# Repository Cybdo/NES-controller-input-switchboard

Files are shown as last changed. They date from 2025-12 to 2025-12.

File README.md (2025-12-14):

# NES-controller-input-switchboard
The switchboard is essentially a 2:2 6-channel multiplexer, with one output being routed to an RP2040 for processing and a USB Keyboard output as opposed to exposing it directly.
Part of a larger homemade arcade project, I want to be able to have a embedded controller with arcade buttons and an external connector for external controllers or a light zapper, to be routed to an NES for retro games, as well as a ZimaBoard or Pi 4 (or other computer, via USB) for modern games

## Features:
- 6 channel 2:2 multiplexer
- ability to switch a power line
- NES Controller signal decode
- USB-HID keyboard output for decoded signals
- Separate data and power USB-C connectors
- ~~Exposed GPIO for expansion~~



## Schematics




## Board


## Firmware
Thanks to [Print 'N Play](https://www.youtube.com/@PrintNPlay) ([Github](https://github.com/printnplay)) for opensourcing a [CircuitPython Script](https://github.com/printnplay/Pico-MicroPython/blob/main/NES2USB.py) that already performs my desired functionailty. If I feel up to it I may rewrite it myself in the future.

## JLCPCB order


## Credits
This project uses work from:
- [Kicad](https://www.kicad.org/)
- [CircuitPython](https://circuitpython.org/)
- [Print 'N Play](https://github.com/printnplay)
- [Hack Club!](https://hackclub.com)

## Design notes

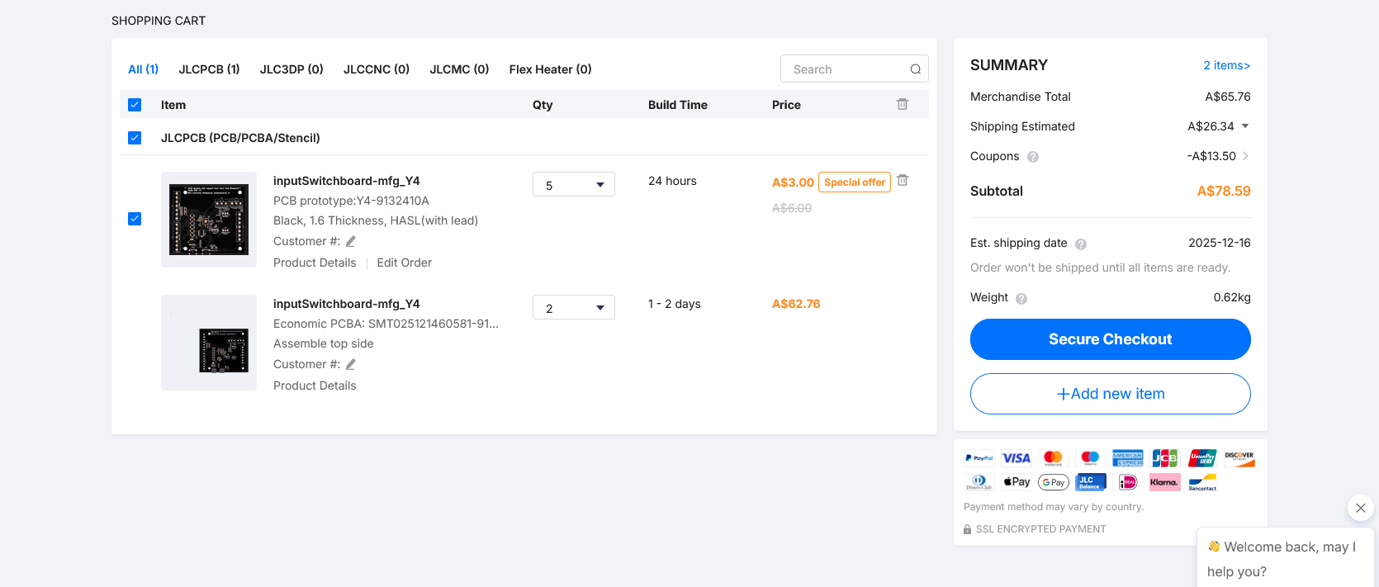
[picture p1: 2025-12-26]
jlcpcb-cart.png

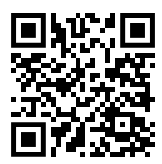
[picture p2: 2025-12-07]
inputSwitchboard/rickroll.bmp

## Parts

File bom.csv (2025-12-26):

Quantity | Item | Price each (AUD) | Price each (USD @ 0.67 USD for 1 AUD) | Price total (USD) | Source
1 | PCB | 3 | 2.01 | 2.01 | JLCPCB
1 | PCBA | 62.76 | 42.05 | 42.05 | JLCPCB
1 | Shipping - PCB | 26.34 | 17.65 | 17.65 | UPS Worldwide Express Saver
2 | NES controller extension cable | 1.59 | 1.07 | 2.13 | Aliexpress - 3Cc Game Store (https://www.aliexpress.com/item/1005003367500150.html)
1 | Shipping - Aliexpress | 5.94 | 3.98 | 3.98 | Aliexpress
 |  |  | total (USD) | 67.82

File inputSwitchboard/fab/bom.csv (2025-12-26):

Id | Designator | Footprint | Quantity | Comment | Supplier and ref
1 | , |  | 2
2 | C5,C13 | C_0201_0603Metric | 2 | 1uF
3 | C11,C15,C16,C12,C6,C10,C8,C14,C9,C7 | C_0201_0603Metric | 10 | 100nF
4 | C17,C18 | C_0201_0603Metric | 2 | 15pF
5 | Y1 | XTAL_ABM8-272-T3 | 1 | ABM8-272-T3
6 | J1 | TYPE-C-31-M-12 | 1 | DATA
7 | R6,R17,R7,R5,R8,R15,R16 | R_0603_1608Metric | 7 | 4k7R
8 | U9 | TSSOP-20_4.4x6.5mm_P0.65mm | 1 | TXS0108EPW
9 | J2 | TYPE-C-31-M-12 | 1 | POWER
10 | C2,C1,C4,C3 | C_0201_0603Metric | 4 | 10uF
11 | R11,R3,R1,R10,R2 | R_0603_1608Metric | 5 | 5k1R
12 | D2 | LED_0201_0603Metric | 1 | STATUS
13 | R19,R18 | R_0603_1608Metric | 2 | 6k8R
14 | U4,U8,U3,U7,U5,U6 | MSOP-10-1EP_3x3mm_P0.5mm_EP1.68x1.88mm | 6 | CH442E
15 | R9,R4 | R_0603_1608Metric | 2 | 470R
16 | R12,R14 | R_0603_1608Metric | 2 | 1kR
17 | U12,U11 | SOT-23-5 | 2 | ~
18 | U10 | SOIC-8_5.3x5.3mm_P1.27mm | 1 | W25Q128JVS
19 | U2 | QFN-56-1EP_7x7mm_P0.4mm_EP3.2x3.2mm | 1 | RP2040
20 | D1 | LED_0201_0603Metric | 1 | PWR_LED
21 | R13 | R_0603_1608Metric | 1 | 10kR
22 | U1 | SOT-223-3_TabPin2 | 1 | AMS1117-3.3

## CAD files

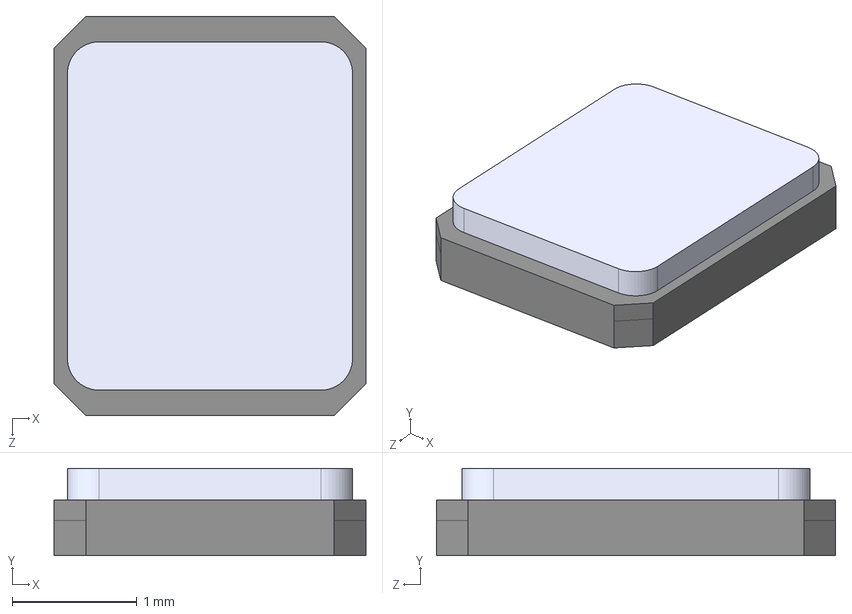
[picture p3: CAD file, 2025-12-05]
inputSwitchboard/imports/ABM8-272-T3.step
2.50 x 0.7 x 3.20 mm

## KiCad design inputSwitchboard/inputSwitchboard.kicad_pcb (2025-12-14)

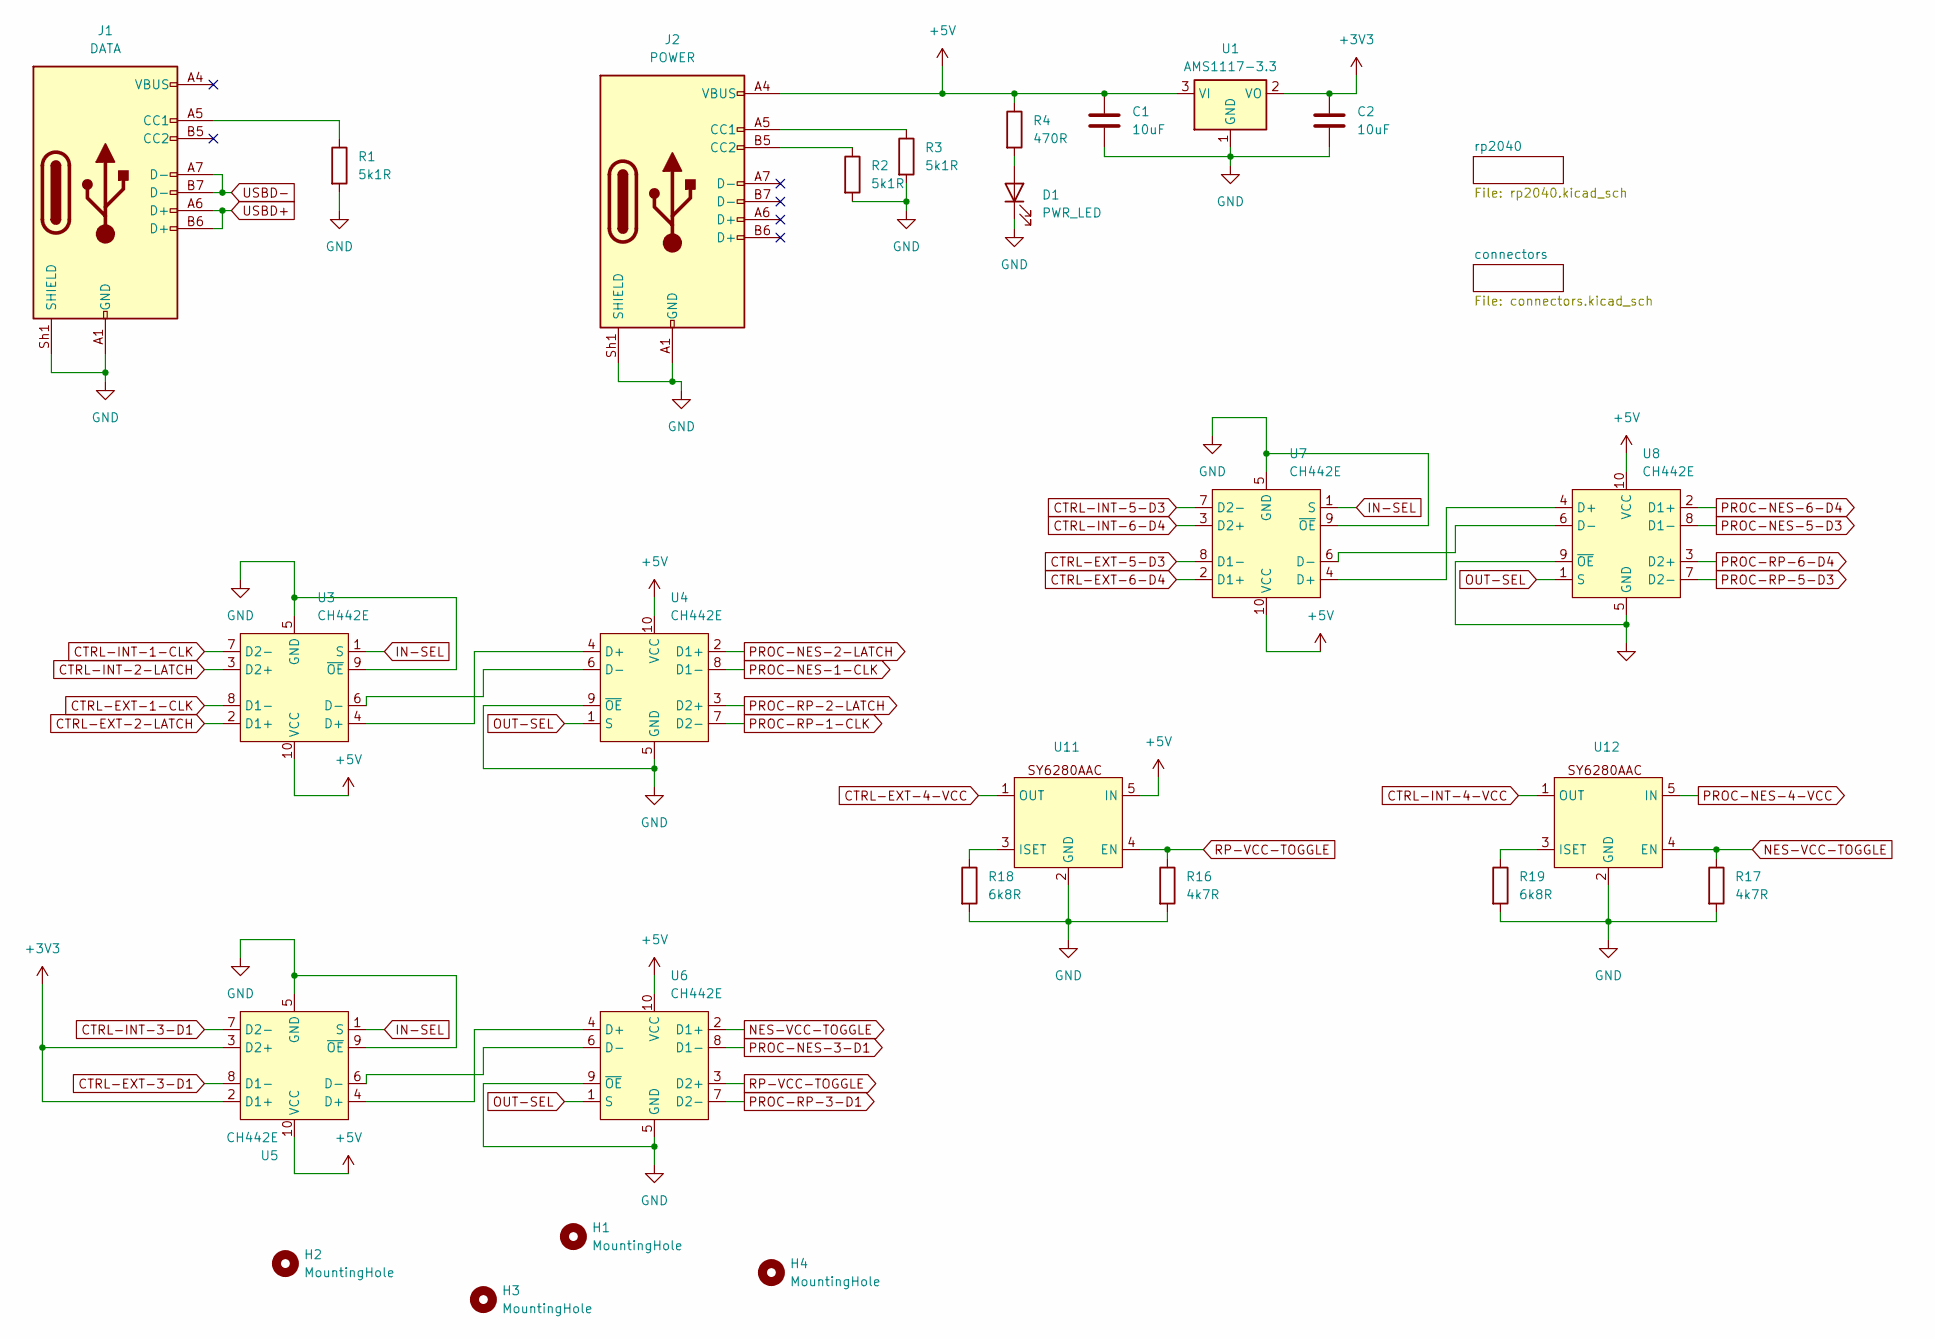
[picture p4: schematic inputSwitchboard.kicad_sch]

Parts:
C1, C2: 10uF; C_0201_0603Metric
D1: PWR_LED; LED_0603_1608Metric
H1, H2, H3, H4: MountingHole; MountingHole_4.3mm_M4
J1: DATA; TYPE-C-31-M-12
J2: POWER; TYPE-C-31-M-12
R1, R2, R3: 5k1R; R_0603_1608Metric
R4: 470R; R_0603_1608Metric
R16, R17: 4k7R; R_0603_1608Metric
R18, R19: 6k8R; R_0603_1608Metric
U1: AMS1117-3.3; SOT-223-3_TabPin2
U3, U4, U5, U6, U7, U8: CH442E; VSSOP-10_3x3mm_P0.5mm
U11, U12: SOT-23-5

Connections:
+3V3: C2.1, U1.2 (VO), U5.2 (D1+), U5.3 (D2+); also elsewhere on the board
+5V: C1.1, J2.A4 (VBUS), J2.A9 (VBUS), J2.B4 (VBUS), J2.B9 (VBUS), R4.1, U1.3 (VI), U3.10 (VCC), U4.10 (VCC), U5.10 (VCC), U6.10 (VCC), U7.10 (VCC), U8.10 (VCC), U11.5 (IN); also elsewhere on the board
CTRL-EXT-1-CLK: U3.8 (D1-); also elsewhere on the board
CTRL-EXT-2-LATCH: U3.2 (D1+); also elsewhere on the board
CTRL-EXT-3-D1: U5.8 (D1-); also elsewhere on the board
CTRL-EXT-4-VCC: U11.1 (OUT); also elsewhere on the board
CTRL-EXT-5-D3: U7.8 (D1-); also elsewhere on the board
CTRL-EXT-6-D4: U7.2 (D1+); also elsewhere on the board
CTRL-INT-1-CLK: U3.7 (D2-); also elsewhere on the board
CTRL-INT-2-LATCH: U3.3 (D2+); also elsewhere on the board
CTRL-INT-3-D1: U5.7 (D2-); also elsewhere on the board
CTRL-INT-4-VCC: U12.1 (OUT); also elsewhere on the board
CTRL-INT-5-D3: U7.7 (D2-); also elsewhere on the board
CTRL-INT-6-D4: U7.3 (D2+); also elsewhere on the board
GND: C1.2, C2.2, D1.1 (K), J1.A1 (GND), J1.A12 (GND), J1.B1 (GND), J1.B12 (GND), J1.Sh1 (SHIELD), J2.A1 (GND), J2.A12 (GND), J2.B1 (GND), J2.B12 (GND), J2.Sh1 (SHIELD), R1.2, R2.2, R3.2, R16.2, R17.2, R18.2, R19.2, U1.1 (GND), U3.5 (GND), U3.9 (~OE), U4.5 (GND), U4.9 (~OE), U5.5 (GND), U5.9 (~OE), U6.5 (GND), U6.9 (~OE), U7.5 (GND), U7.9 (~OE), U8.5 (GND), U8.9 (~OE), U11.2 (GND), U12.2 (GND); also elsewhere on the board
IN-SEL: U3.1 (S), U5.1 (S), U7.1 (S); also elsewhere on the board
NES-VCC-TOGGLE: R17.1, U6.2 (D1+), U12.4 (EN)
unnamed: D1.2 (A), R4.2
unnamed: J1.A5 (CC1), R1.1
unnamed: J2.A5 (CC1), R3.1
unnamed: J2.B5 (CC2), R2.1
unnamed: U3.4 (D+), U4.4 (D+)
unnamed: U3.6 (D-), U4.6 (D-)
unnamed: U5.4 (D+), U6.4 (D+)
unnamed: U5.6 (D-), U6.6 (D-)
unnamed: U7.4 (D+), U8.4 (D+)
unnamed: U7.6 (D-), U8.6 (D-)
unnamed: R18.1, U11.3 (ISET)
unnamed: R19.1, U12.3 (ISET)
OUT-SEL: U4.1 (S), U6.1 (S), U8.1 (S); also elsewhere on the board
PROC-NES-1-CLK: U4.8 (D1-); also elsewhere on the board
PROC-NES-2-LATCH: U4.2 (D1+); also elsewhere on the board
PROC-NES-3-D1: U6.8 (D1-); also elsewhere on the board
PROC-NES-4-VCC: U12.5 (IN); also elsewhere on the board
PROC-NES-5-D3: U8.8 (D1-); also elsewhere on the board
PROC-NES-6-D4: U8.2 (D1+); also elsewhere on the board
PROC-RP-1-CLK: U4.7 (D2-); also elsewhere on the board
PROC-RP-2-LATCH: U4.3 (D2+); also elsewhere on the board
PROC-RP-3-D1: U6.7 (D2-); also elsewhere on the board
PROC-RP-5-D3: U8.7 (D2-); also elsewhere on the board
PROC-RP-6-D4: U8.3 (D2+); also elsewhere on the board
RP-VCC-TOGGLE: R16.1, U6.3 (D2+), U11.4 (EN)
USBD+: J1.A6 (D+), J1.B6 (D+); also elsewhere on the board
USBD-: J1.A7 (D-), J1.B7 (D-); also elsewhere on the board

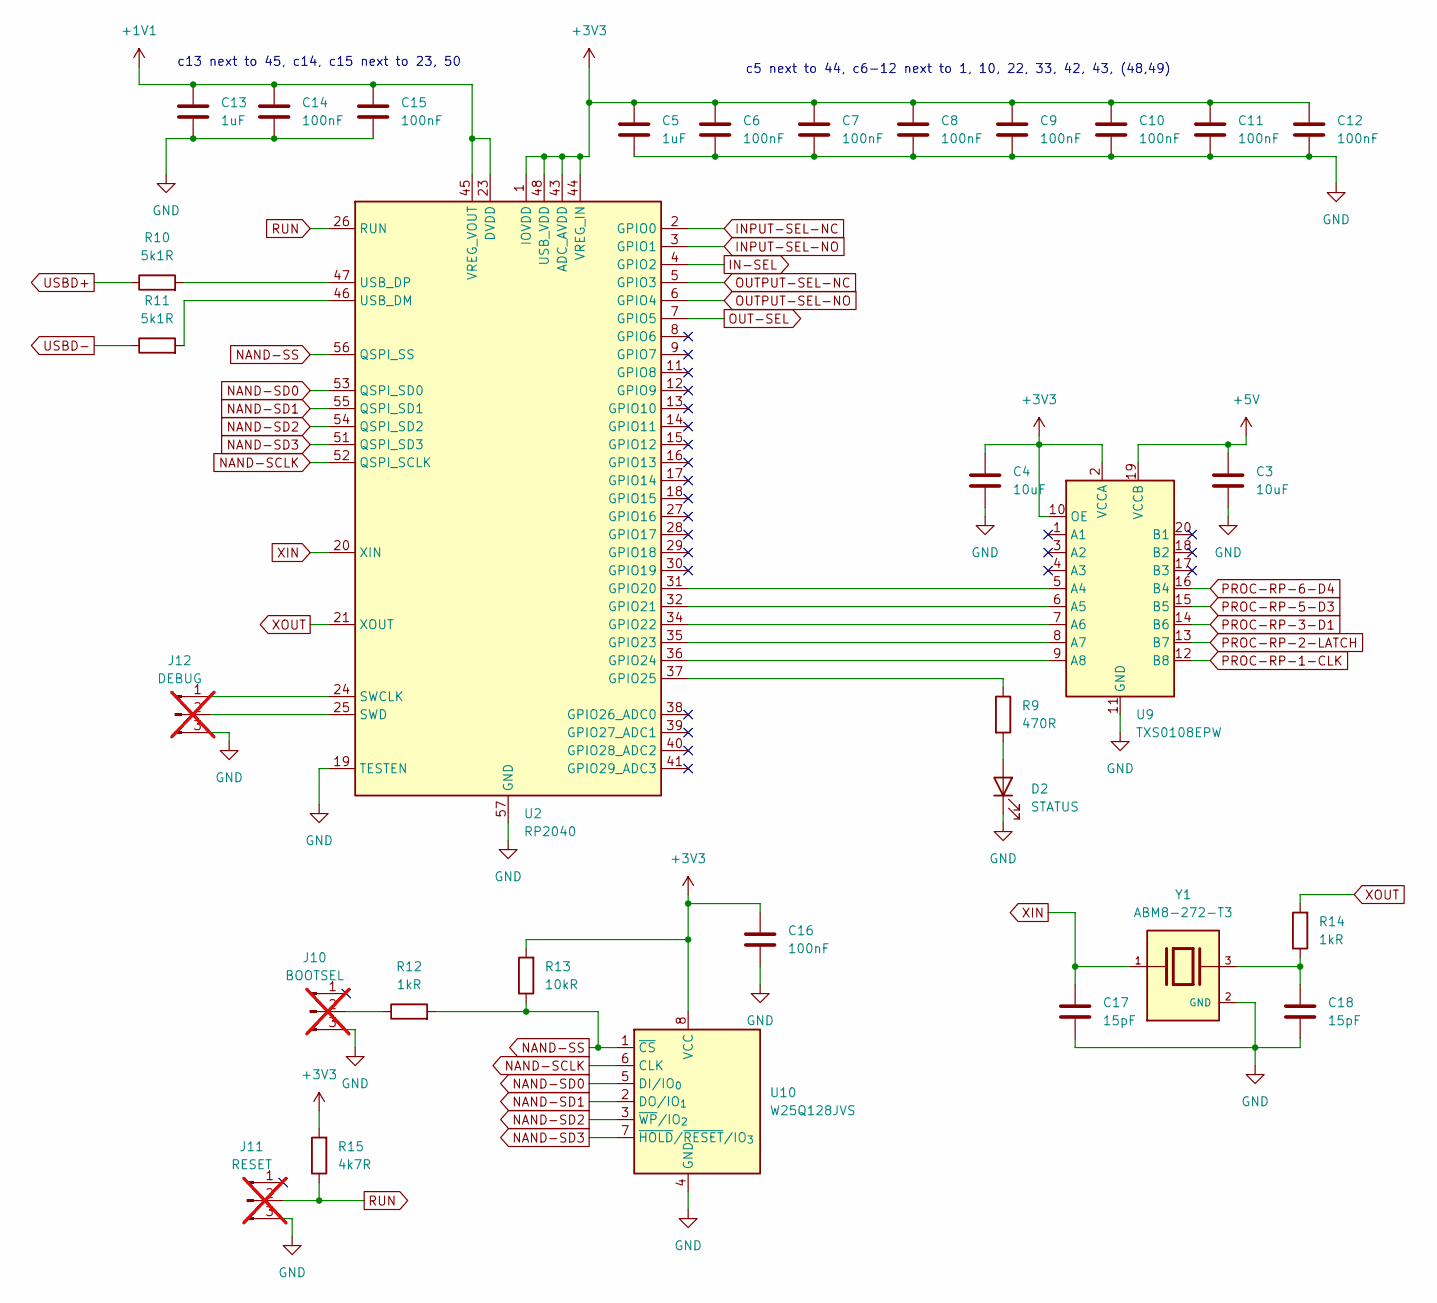
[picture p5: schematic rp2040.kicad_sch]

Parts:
C3, C4: 10uF; C_0201_0603Metric
C5, C13: 1uF; C_0201_0603Metric
C6, C7, C8, C9, C10, C11, C12, C14, C15, C16: 100nF; C_0201_0603Metric
C17, C18: 15pF; C_0201_0603Metric
D2: STATUS; LED_0603_1608Metric
J10: BOOTSEL; FanPinHeader_1x03_P2.54mm_Vertical; not fitted
J11: RESET; FanPinHeader_1x03_P2.54mm_Vertical; not fitted
J12: DEBUG; FanPinHeader_1x03_P2.54mm_Vertical; not fitted
R9: 470R; R_0603_1608Metric
R10, R11: 5k1R; R_0603_1608Metric
R12, R14: 1kR; R_0603_1608Metric
R13: 10kR; R_0603_1608Metric
R15: 4k7R; R_0603_1608Metric
U2: RP2040; QFN-56-1EP_7x7mm_P0.4mm_EP3.2x3.2mm
U9: TXS0108EPW; TSSOP-20_4.4x6.5mm_P0.65mm
U10: W25Q128JVS; SOIC-8_5.3x5.3mm_P1.27mm
Y1: ABM8-272-T3; XTAL_ABM8-272-T3; PARTREV 07-29-20

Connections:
+1V1: C13.1, C14.1, C15.1, U2.23 (DVDD), U2.45 (VREG_VOUT), U2.50 (DVDD)
+3V3: C4.1, C5.1, C6.1, C7.1, C8.1, C9.1, C10.1, C11.1, C12.1, C16.1, R13.2, R15.2, U2.1 (IOVDD), U2.10 (IOVDD), U2.22 (IOVDD), U2.33 (IOVDD), U2.42 (IOVDD), U2.43 (ADC_AVDD), U2.44 (VREG_IN), U2.48 (USB_VDD), U2.49 (IOVDD), U9.2 (VCCA), U9.10 (OE), U10.8 (VCC); also elsewhere on the board
+5V: C3.1, U9.19 (VCCB); also elsewhere on the board
GND: C3.2, C4.2, C5.2, C6.2, C7.2, C8.2, C9.2, C10.2, C11.2, C12.2, C13.2, C14.2, C15.2, C16.2, C17.2, C18.2, D2.1 (K), J10.3, J11.3, J12.3, U2.19 (TESTEN), U2.57 (GND), U9.11 (GND), U10.4 (GND), Y1.2 (GND), Y1.4 (GND); also elsewhere on the board
IN-SEL: U2.4 (GPIO2); also elsewhere on the board
INPUT-SEL-NC: U2.2 (GPIO0); also elsewhere on the board
INPUT-SEL-NO: U2.3 (GPIO1); also elsewhere on the board
NAND-SCLK: U2.52 (QSPI_SCLK), U10.6 (CLK)
NAND-SD0: U2.53 (QSPI_SD0), U10.5 (DI/IO_{0})
NAND-SD1: U2.55 (QSPI_SD1), U10.2 (DO/IO_{1})
NAND-SD2: U2.54 (QSPI_SD2), U10.3 (~WP/IO_{2})
NAND-SD3: U2.51 (QSPI_SD3), U10.7 (~HOLD/~RESET/IO_{3})
NAND-SS: R12.2, R13.1, U2.56 (QSPI_SS), U10.1 (~CS)
unnamed: C18.1, R14.1, Y1.3
unnamed: D2.2 (A), R9.2
unnamed: J10.2, R12.1
unnamed: J12.1, U2.24 (SWCLK)
unnamed: J12.2, U2.25 (SWD)
unnamed: U2.31 (GPIO20), U9.5 (A4)
unnamed: U2.32 (GPIO21), U9.6 (A5)
unnamed: U2.34 (GPIO22), U9.7 (A6)
unnamed: U2.35 (GPIO23), U9.8 (A7)
unnamed: U2.36 (GPIO24), U9.9 (A8)
unnamed: R9.1, U2.37 (GPIO25)
unnamed: R11.2, U2.46 (USB_DM)
unnamed: R10.2, U2.47 (USB_DP)
OUT-SEL: U2.7 (GPIO5); also elsewhere on the board
OUTPUT-SEL-NC: U2.5 (GPIO3); also elsewhere on the board
OUTPUT-SEL-NO: U2.6 (GPIO4); also elsewhere on the board
PROC-RP-1-CLK: U9.12 (B8); also elsewhere on the board
PROC-RP-2-LATCH: U9.13 (B7); also elsewhere on the board
PROC-RP-3-D1: U9.14 (B6); also elsewhere on the board
PROC-RP-5-D3: U9.15 (B5); also elsewhere on the board
PROC-RP-6-D4: U9.16 (B4); also elsewhere on the board
RUN: J11.2, R15.1, U2.26 (RUN)
USBD+: R10.1; also elsewhere on the board
USBD-: R11.1; also elsewhere on the board
XIN: C17.1, U2.20 (XIN), Y1.1
XOUT: R14.2, U2.21 (XOUT)

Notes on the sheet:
c5 next to 44, c6-12 next to 1, 10, 22, 33, 42, 43, (48,49)
c13 next to 45, c14, c15 next to 23, 50

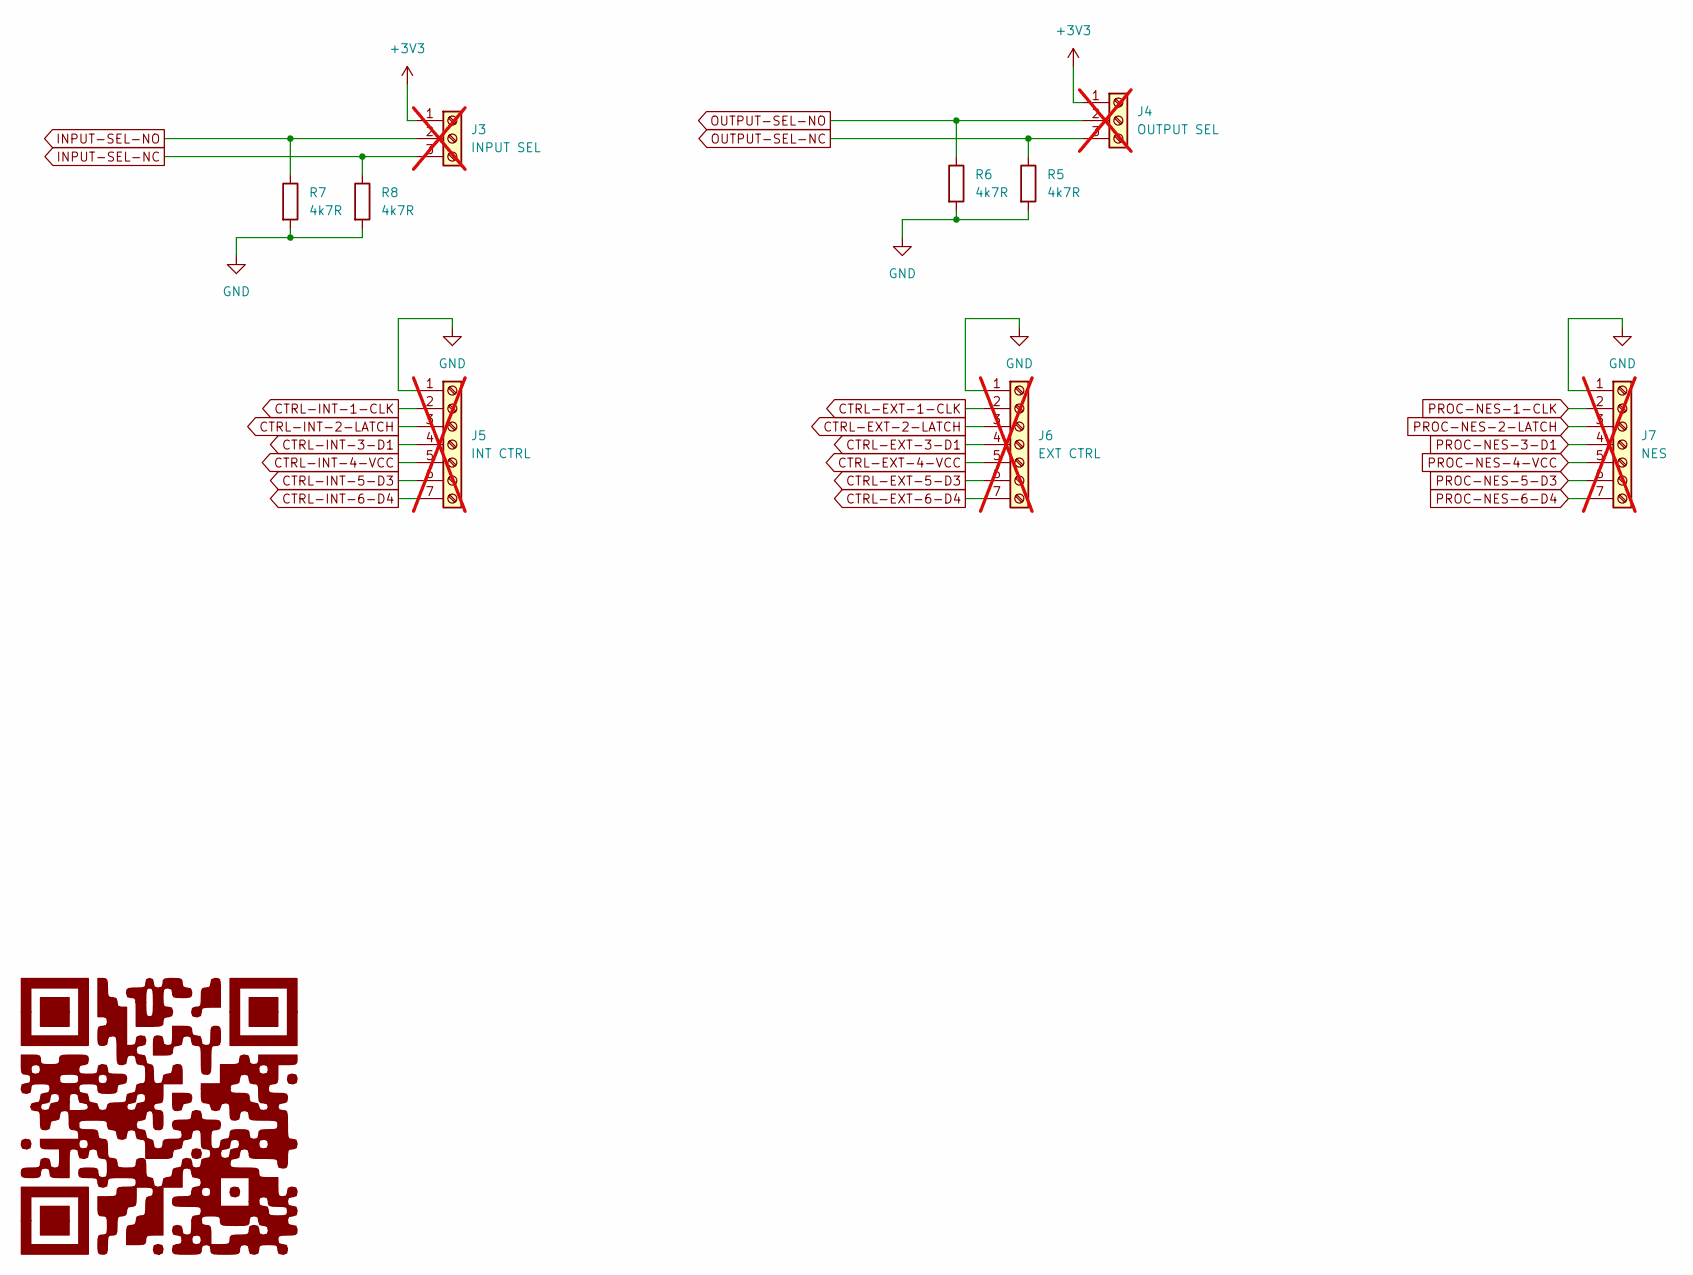
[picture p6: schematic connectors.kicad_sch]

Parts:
J3: INPUT SEL; TerminalBlock_Phoenix_MKDS-1,5-3-5.08_1x03_P5.08mm_Horizont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; not fitted
J4: OUTPUT SEL; TerminalBlock_Phoenix_MKDS-1,5-3-5.08_1x03_P5.08mm_Horizont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; not fitted
J5: INT CTRL; TerminalBlock_MaiXu_MX126-5.0-07P_1x07_P5.00mm; not fitted
J6: EXT CTRL; TerminalBlock_MaiXu_MX126-5.0-07P_1x07_P5.00mm; not fitted
J7: NES; TerminalBlock_MaiXu_MX126-5.0-07P_1x07_P5.00mm; not fitted
R5, R6, R7, R8: 4k7R; R_0603_1608Metric

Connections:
+3V3: J3.1, J4.1; also elsewhere on the board
CTRL-EXT-1-CLK: J6.2; also elsewhere on the board
CTRL-EXT-2-LATCH: J6.3; also elsewhere on the board
CTRL-EXT-3-D1: J6.4; also elsewhere on the board
CTRL-EXT-4-VCC: J6.5; also elsewhere on the board
CTRL-EXT-5-D3: J6.6; also elsewhere on the board
CTRL-EXT-6-D4: J6.7; also elsewhere on the board
CTRL-INT-1-CLK: J5.2; also elsewhere on the board
CTRL-INT-2-LATCH: J5.3; also elsewhere on the board
CTRL-INT-3-D1: J5.4; also elsewhere on the board
CTRL-INT-4-VCC: J5.5; also elsewhere on the board
CTRL-INT-5-D3: J5.6; also elsewhere on the board
CTRL-INT-6-D4: J5.7; also elsewhere on the board
GND: J5.1, J6.1, J7.1, R5.2, R6.2, R7.2, R8.2; also elsewhere on the board
INPUT-SEL-NC: J3.3, R8.1; also elsewhere on the board
INPUT-SEL-NO: J3.2, R7.1; also elsewhere on the board
OUTPUT-SEL-NC: J4.3, R5.1; also elsewhere on the board
OUTPUT-SEL-NO: J4.2, R6.1; also elsewhere on the board
PROC-NES-1-CLK: J7.2; also elsewhere on the board
PROC-NES-2-LATCH: J7.3; also elsewhere on the board
PROC-NES-3-D1: J7.4; also elsewhere on the board
PROC-NES-4-VCC: J7.5; also elsewhere on the board
PROC-NES-5-D3: J7.6; also elsewhere on the board
PROC-NES-6-D4: J7.7; also elsewhere on the board

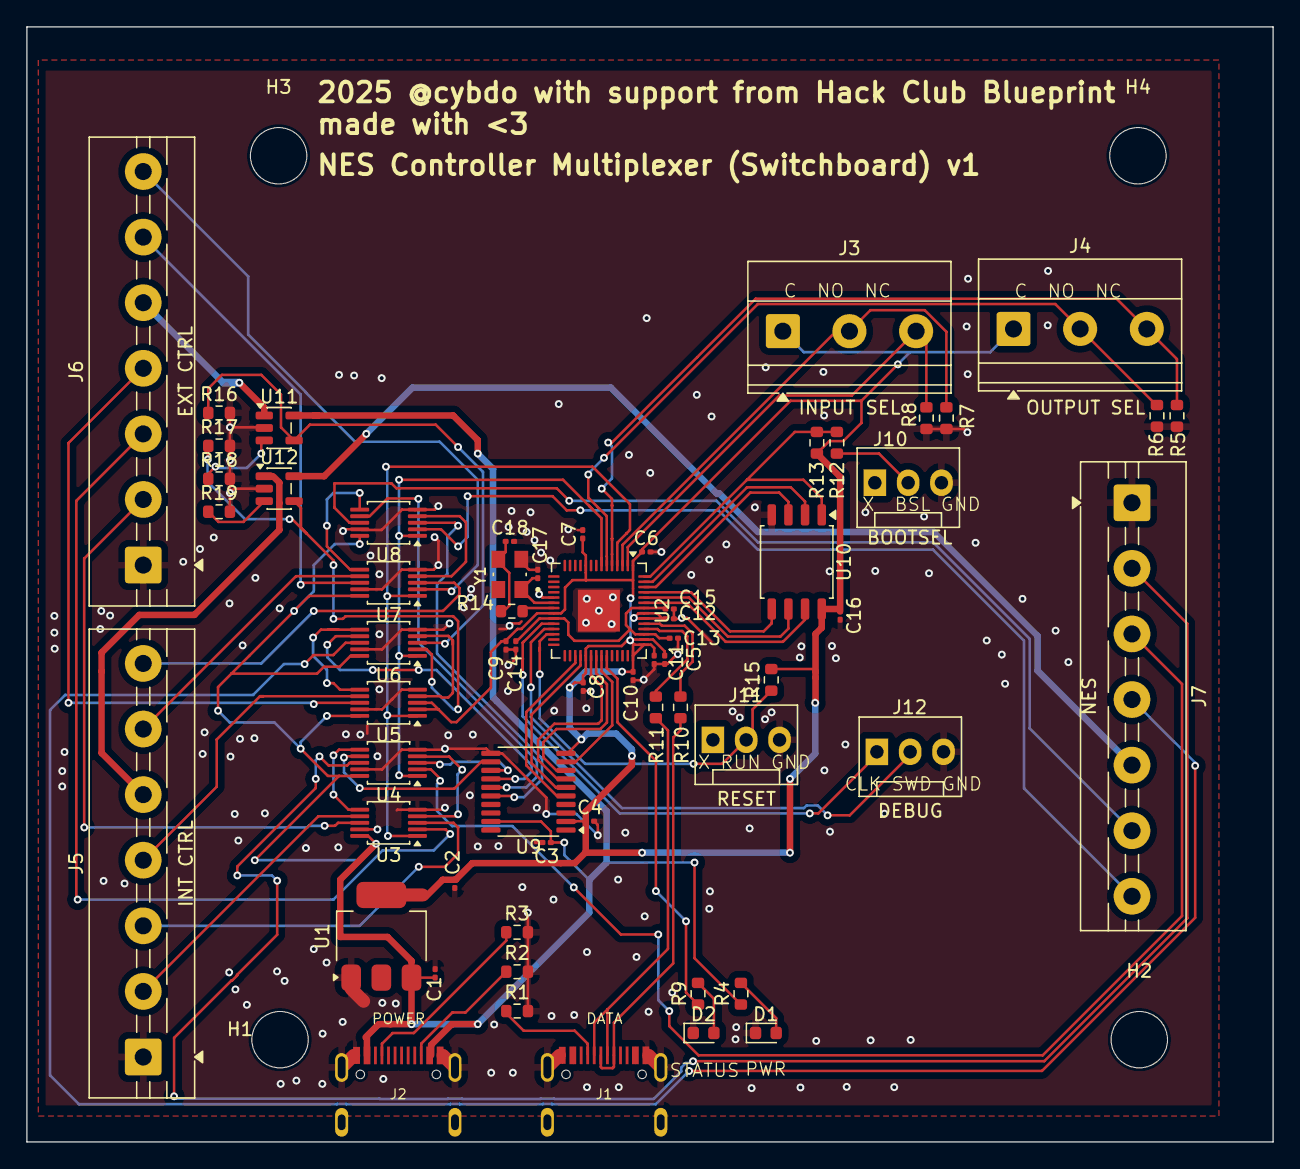
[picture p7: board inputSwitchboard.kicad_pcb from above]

Board: 2 copper layers, 95.0 x 85.0 mm, 66 parts (0 on the bottom side), 71 nets.

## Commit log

2025-12-03 journal 2
    [connectors.kicad_sch, inputSwitchboard.kicad_pcb, inputSwitchboard.kicad_sch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]
2025-12-05 finished schematic
    [ABM8-272-T3.step, connectors.kicad_sch, inputSwitchboard.kicad_sch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]
2025-12-06 Proofread, started to route
    [connectors.kicad_sch, inputSwitchboard.kicad_pcb, inputSwitchboard.kicad_sch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]
2025-12-07 finished routing
    [connectors.kicad_sch, inputSwitchboard.kicad_pcb, rp2040.kicad_sch]
2025-12-07 fixed more stuff and polished routing
    [connectors.kicad_sch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]
2025-12-14 update manufacture files, create BOM
    [inputSwitchboard-B_Cu.gbr, inputSwitchboard-B_Mask.gbr, inputSwitchboard-B_Paste.gbr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]
2025-12-26 csvs got gitignored :sob:
    [bom.csv, inputSwitchboard.csv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]
